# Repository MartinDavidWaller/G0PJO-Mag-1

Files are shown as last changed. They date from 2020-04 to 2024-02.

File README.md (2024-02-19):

# G0PJO Mag-1

 This is my take on a magnetic iambic paddle.
 
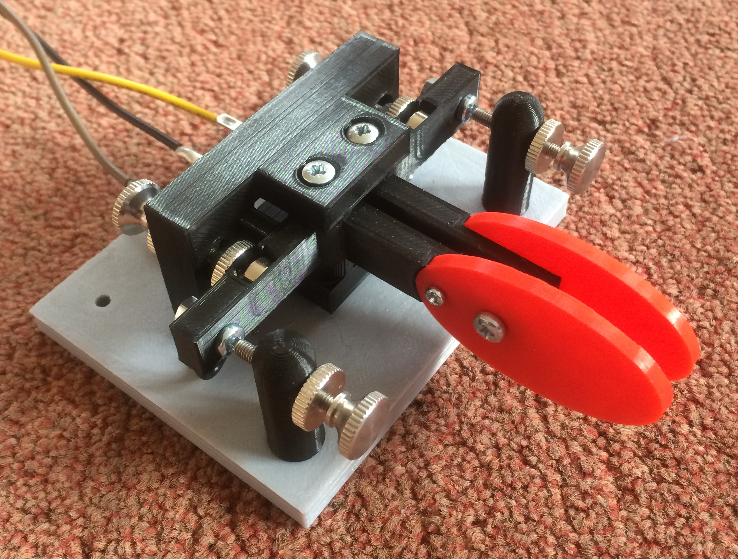
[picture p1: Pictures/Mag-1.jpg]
  
 
 For a demo click the following like: <https://1drv.ms/v/s!AnVoR6zEVAnDpdU-3a5iHmETETuGXw?e=P3bwG2>
 
 ## Required Parts
 
 The following parts are all 3D printed. The table below details the part, the colour, the infill, 
 and the approximate length, and weight, of PLA required. If parts seem too 'bendy' then you may like to increase
 the infill percentage when printing.

| Part | Colour | Quantity | Infill % | Total Length | Total Weight |
|---|---|---|---|---|---|
| Base | Grey | 1 | 20% | 6.62m |  20g |
| Binding Post	 | Black  | 3 | 20%	 | 0.33m | < 1g |
| Dah Lever Arm | Black  | 1 | 80%	 | 1.62m | 5g |
| Dih Lever Arm	 | Black  | 1 | 80%	 | 1.62m | 5g |
| Lever Plate	 | Red | 2 | 20%	 | 1.56m | 4g |
| Main Frame	 | Black  | 1 | 20%	 | 4.90m |  15g
| Short Contact Post | Black  | 2 | 20%	 | 1.14m | 4g

Total length of PLA required 17.79m, total weight 53g.

The table below details all the additional hardware, nuts & bolts etc.

| Part | Quantity | See Note |
| --- | ---| --- |
| M2 Bolt 6mm | 2 | 1 |
| M2 Nut | 2 | 1 |
| M3 Bolt 6mm | 4 | 1 |
| M3 Bolt 16mm | 7 | 1 |
| M3 Bolt 30mm | 2 | 2 |
| M3 Knurled Bolt 20mm | 4 | 6 |
| M3 Knurled Thumb Nut | 3 | 5 |
| M3 Knurled Nut | 6 | 4 |
| M3 Nut | 17 | 1 |
| M3 Solder Tag | 15 | 1 |
| M3 Washer | 3 | 1 |
| Neodymium Magnets Rare 8mm Diameter by 3mm | 2 | 3 |

Notes:

1. Bought from BitsBox. <https://www.bitsbox.co.uk/>
2. Bought on ebay. <https://www.ebay.co.uk/itm/Pan-Head-M3-Machine-Screws-A2-Stainless-Steel-Phillips-Head-Bolts-Pozi/192055137207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>
3. Bought on ebay. <https://www.ebay.co.uk/itm/Neodymium-Magnets-4mm-5mm-6mm-8mm-10mm-12mm-15mm-neo-magnet-discs-craft-hobby-UK/153421329186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>
4. Bought on ebay. <https://www.ebay.co.uk/itm/Carbon-Steel-Leveling-Round-Knurled-Thumb-Nut-Zinc-Ni-Plated-M2-M2-5-M3-M4-M5-M6/283734043425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> 
5. Bought on ebay. <https://www.ebay.co.uk/itm/M2-M2-5-M3-M4-M5-M6-High-Knurled-Thumb-Nut-Stainless-Steel-Hand-Grip-Knob-Nuts/123896017185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>
6. Bought on ebay. <https://www.ebay.co.uk/itm/Stainless-Steel-Knurled-Thumb-Screws-Hand-Grip-Knob-Bolts-M2-M2-5-M3-M4-M5-M6/283734090984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>

## Assembly

Assembly is quite easy. Below are the steps to follow. The only required tools are a screwdriver and small pliers.

### Step 1

Install 3 binding posts. These provide connections to the keyer. Each post requires:

* M3 Bolt 16mm * 1
* M3 Solder Tag * 1
* Printed Binding Post * 1
* M3 Knurled Thumb Nut * 1
* M3 Nut * 1
* M3 Washer * 1

Expect to bury the nut within the body of the binding post. See the images below for the detailed construction. 

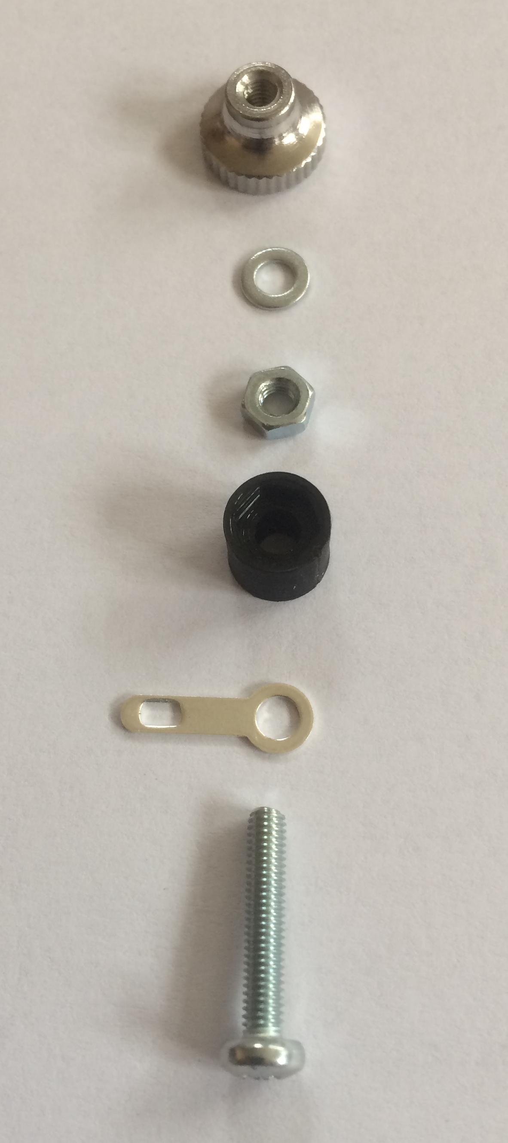
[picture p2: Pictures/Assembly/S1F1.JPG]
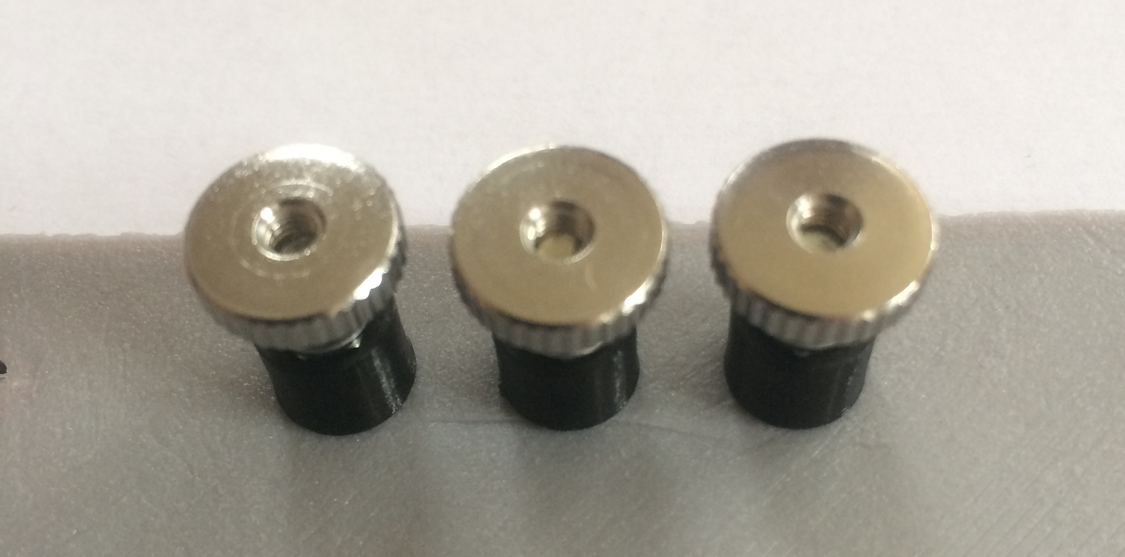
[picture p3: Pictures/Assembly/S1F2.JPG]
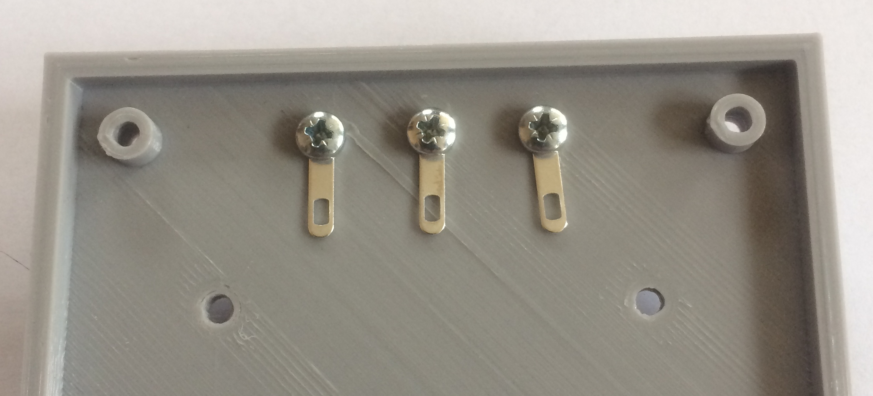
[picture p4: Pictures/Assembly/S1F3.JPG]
  

### Step 2

Build the two arms. Each arm requires:

* Arm * 1
* Lever Plate * 1
* M2 Bolt 6mm * 1
* M2 Nut 
* M3 Bolt 6mm * 2
* M3 Nut * 2
* M3 Solder Tag * 1
* Neodymium Magnet * 1

Expect to bury the nuts within the arms. If you have a problem inserting the nuts into the arm then simply 
use a longer bolt to pull them in to the arm. See the images below for the detailed construction. 

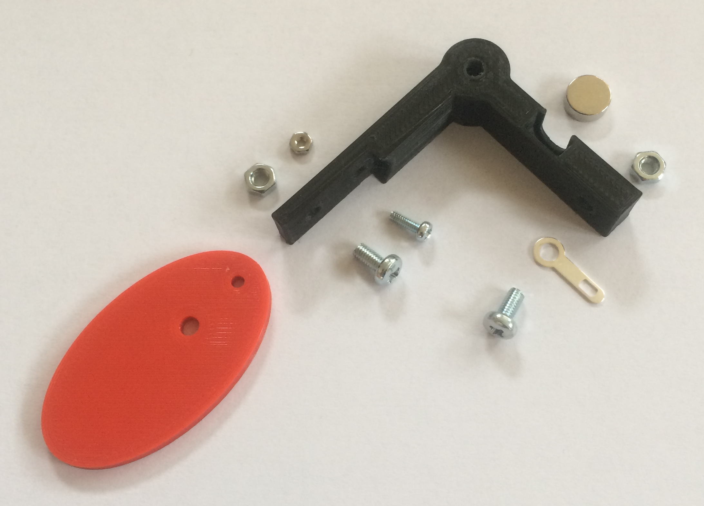
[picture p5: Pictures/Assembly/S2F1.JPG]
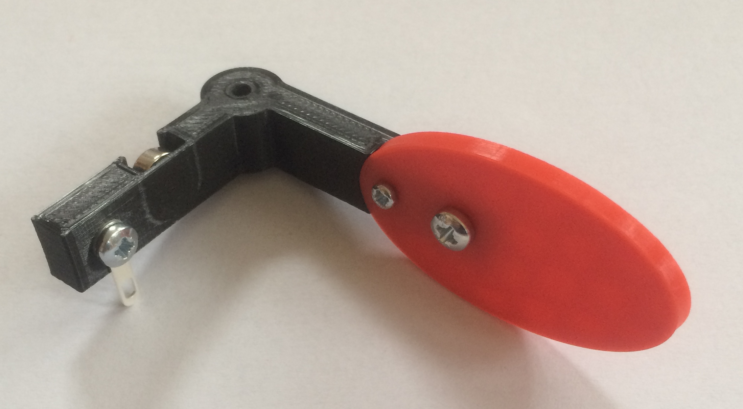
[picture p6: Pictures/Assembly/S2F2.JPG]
  

### Step 3

Assemble the two magnet attraction bolts. Each bolt requires:

* M3 Knurled Bolt 20mm * 1
* M3 Knurled Nut * 2
* M3 Nut * 2

See the images below for the detailed construction. 

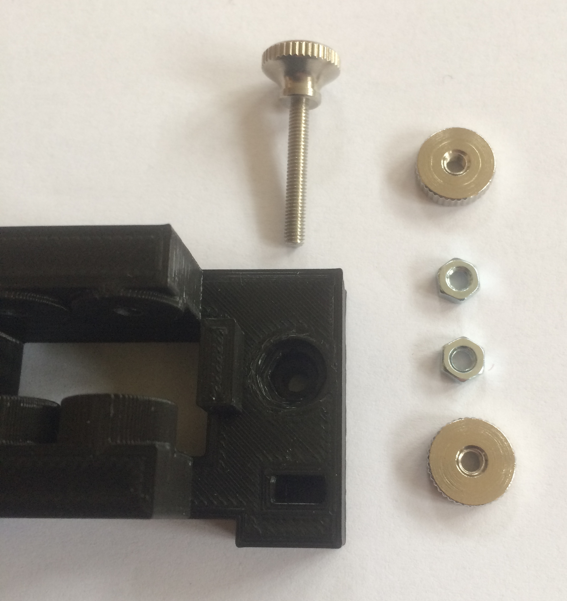
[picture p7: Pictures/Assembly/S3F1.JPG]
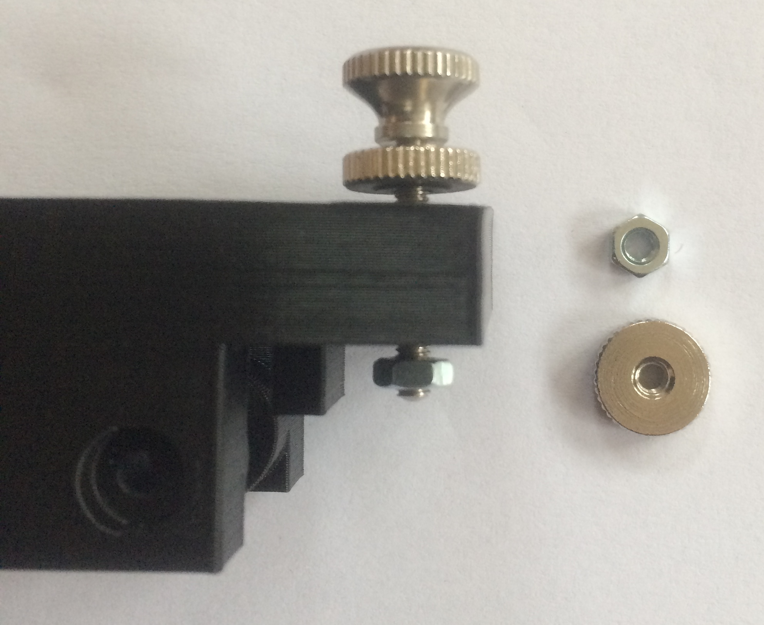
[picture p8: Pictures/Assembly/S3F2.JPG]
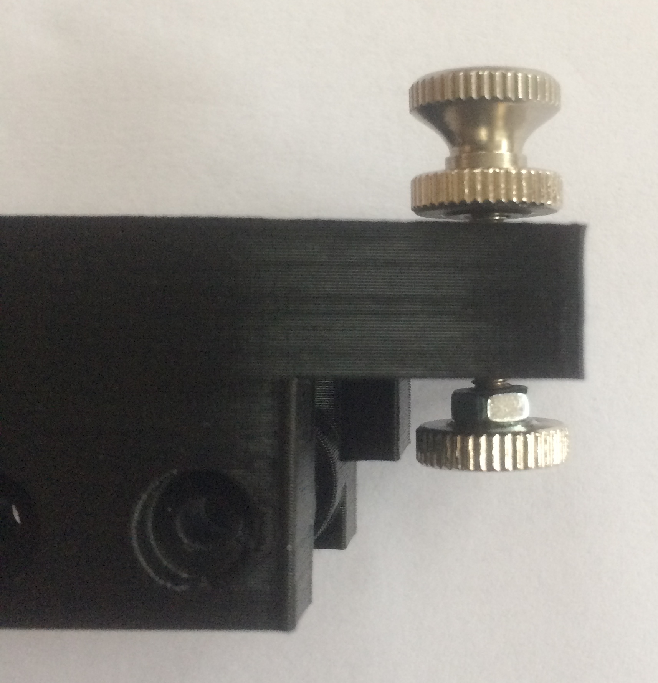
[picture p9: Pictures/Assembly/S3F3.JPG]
   

### Step 4

Assemble the two signal contacts and attach the frame to the base place. Each side requires:

* M3 Bolt 16mm * 2
* M3 Nut * 1
* M3 Solder Tag * 2

The M3 bolt goes through an M3 solder tag, through the base plate into the body, 
though an M3 solder tag and then through the M3 bolt.
See the images below for the detailed construction. 

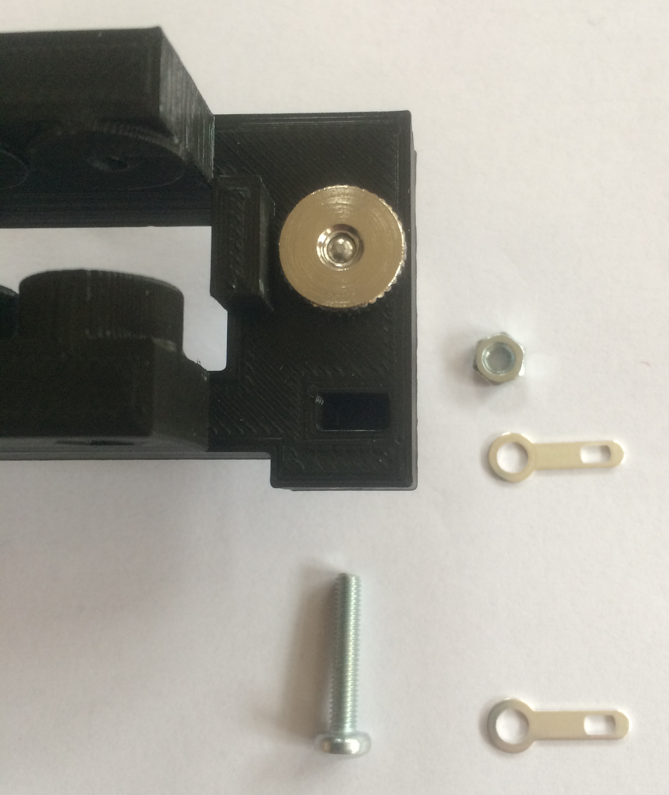
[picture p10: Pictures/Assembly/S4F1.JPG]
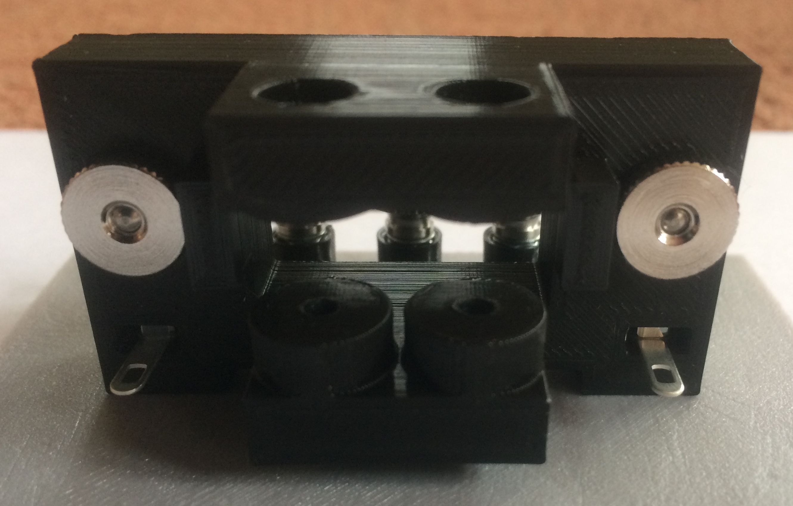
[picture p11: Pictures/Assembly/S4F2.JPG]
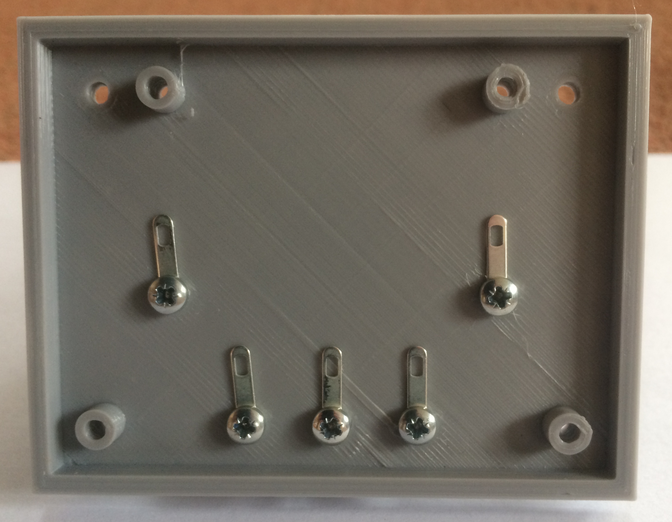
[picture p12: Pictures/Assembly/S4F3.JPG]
   

### Step 5

Assemble the DIT and DAH short contact posts. Each post requires:

* M3 Knurled Bolt 20mm * 1
* M3 Knulred Nut * 1
* M3 Solder Tag * 2
* M3 Nut * 2
* M3 Bolt 16mm * 1
* Printed Short Contact Post * 2

Starting at the top put the knurled nut onto the knurled bolt and screw it all the way down. 
Pass the bolt thought the 3mm hole in the side of the contact post and put one M3 solder 
tag and 3mm nut on the other size and screw home so that the nut is pulled into the contact 
post. At the bottom push the hoop end of a 3mm solder tag into the contact post and above 
that push in a M3 nut. Screw the M3 bolt up through the bottom until it has passed through
the nut. You should then be able to bend the bottom 3mm solder tag over the M3 nut so that 
it makes contact with the upper M3 solder tag. The solder tag can then be soldered together. 
This can be done in situ, but it is best to disassemble and solder them separately.
See the images below for the detailed construction.

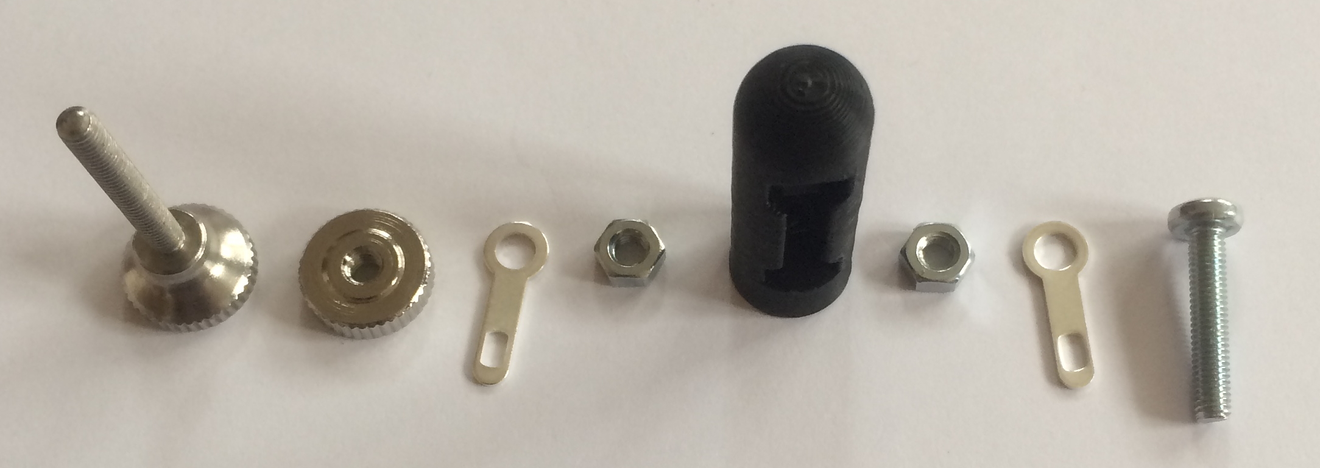
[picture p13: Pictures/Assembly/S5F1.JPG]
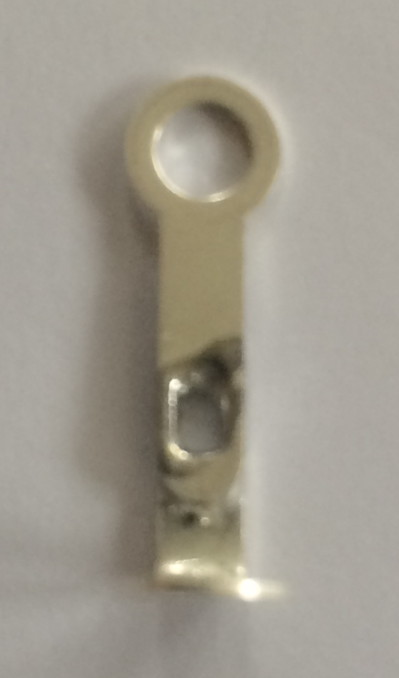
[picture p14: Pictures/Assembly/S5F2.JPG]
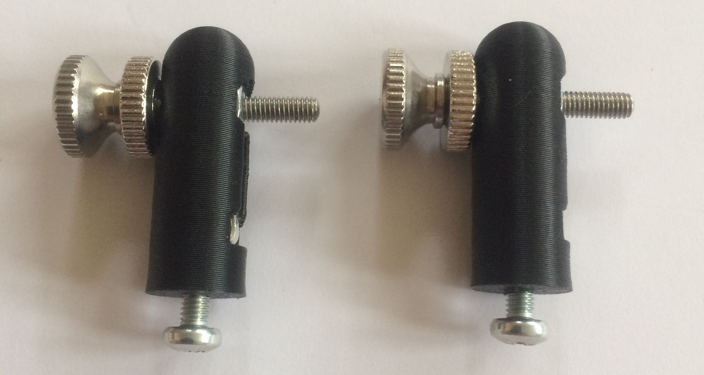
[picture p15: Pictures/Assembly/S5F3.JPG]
  

### Step 6

Attach the DIT and DAH short contact posts to the base. Each post requires:

* M3 Solder Tag * 1
* M3 Bolt 16mm * 1

Pass the bolt through an M3 solder tag and up through the base and into the base of the short contact post. Tighted as required.
See the image below for the detailed construction.

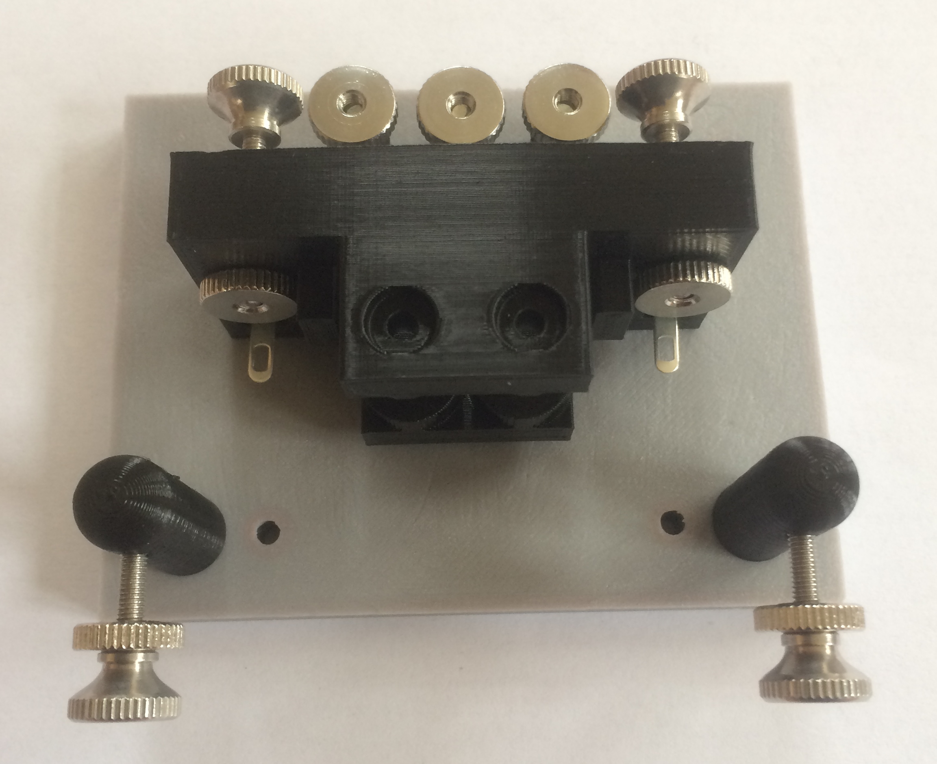
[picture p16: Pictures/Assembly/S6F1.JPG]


### Step 7

Attach the DIT and DAH short arms to the body. Each post require:

* M3 Bolt 30mm * 1

Align the hole in the arm with the hole in the body and drop in the M3 bolt. When adjusted there is sufficient friction to keep
the bolt, and hence the arms in place. There is provision in the bottom of the body for nuts on these two bolts but they
were found not to be necessary. You may need to slightly enlarge these holes with a 3mm drill. If required try to follow the pilot
hole as closely as possible. See the image below for the detailed construction.

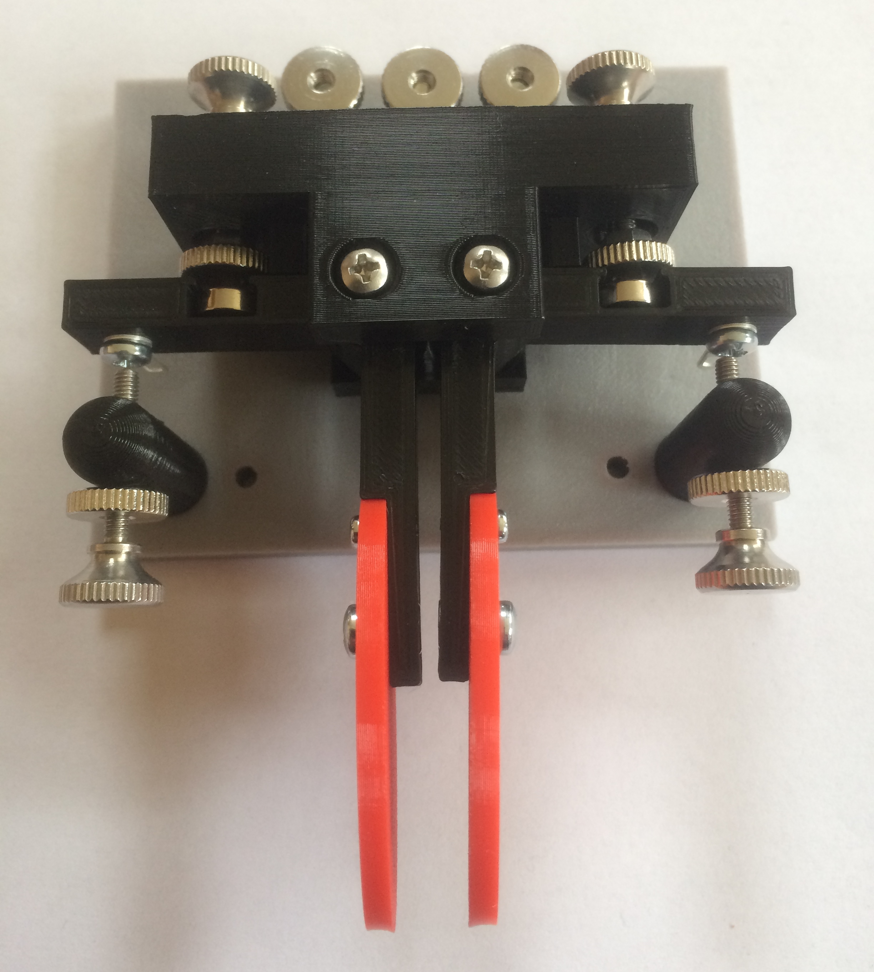
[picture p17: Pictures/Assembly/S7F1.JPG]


### Step 8

Add hook up wires. This requires:

* Assembled keyer * 1
* Short lengths of hook up wire, preferably multi strand.

This is best described by the images below. 

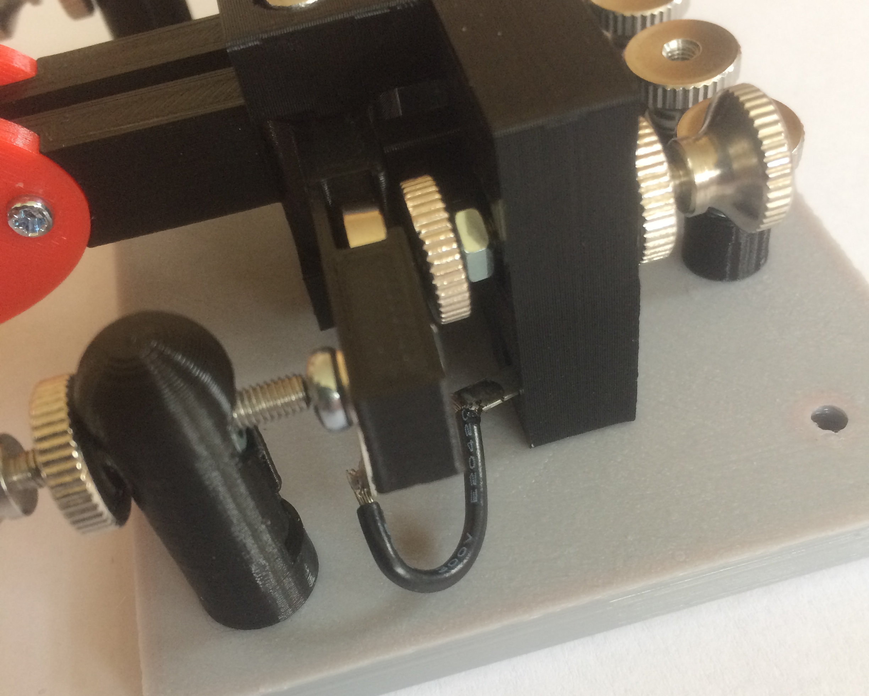
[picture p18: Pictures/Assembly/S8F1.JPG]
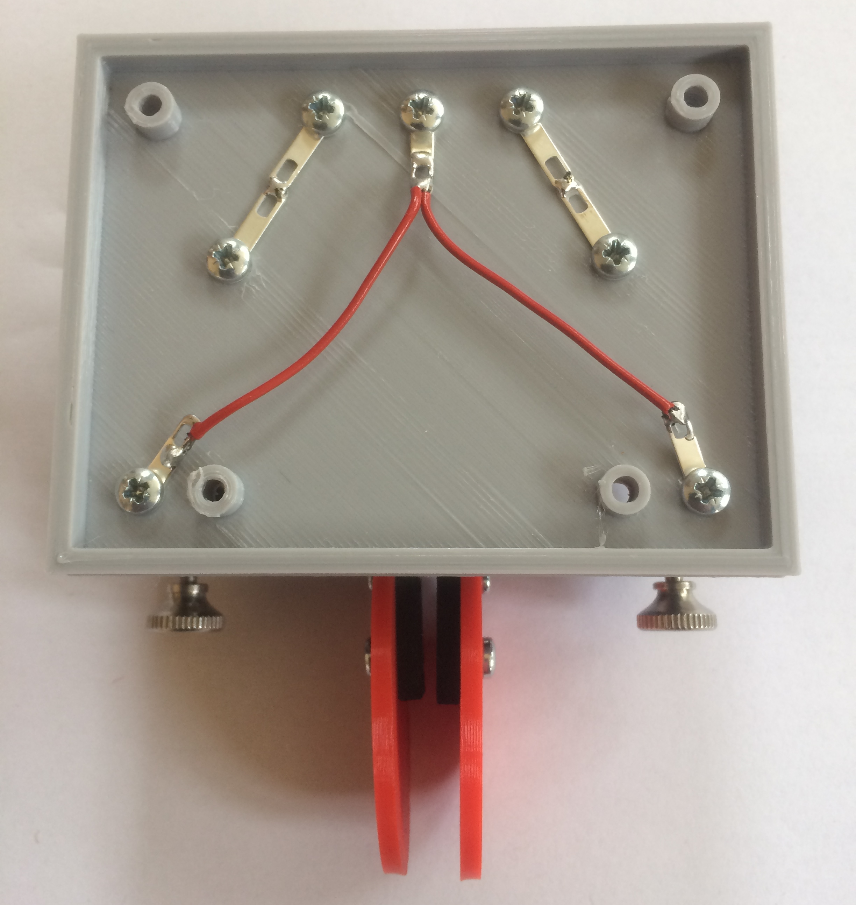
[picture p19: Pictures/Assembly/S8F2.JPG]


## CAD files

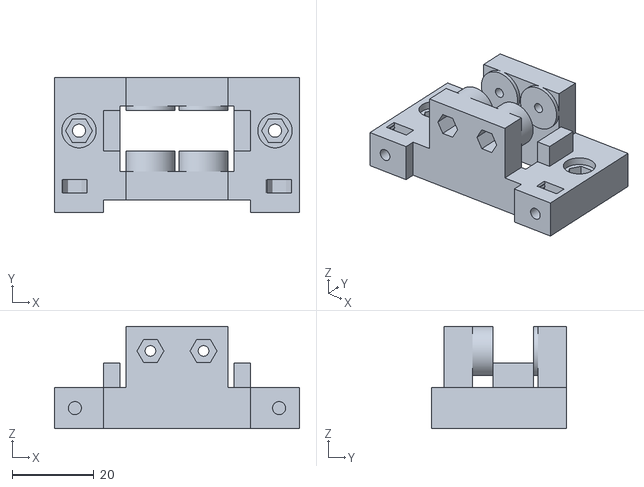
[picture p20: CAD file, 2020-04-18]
STL/MainFrame.stl
60.0 x 33.0 x 25.0

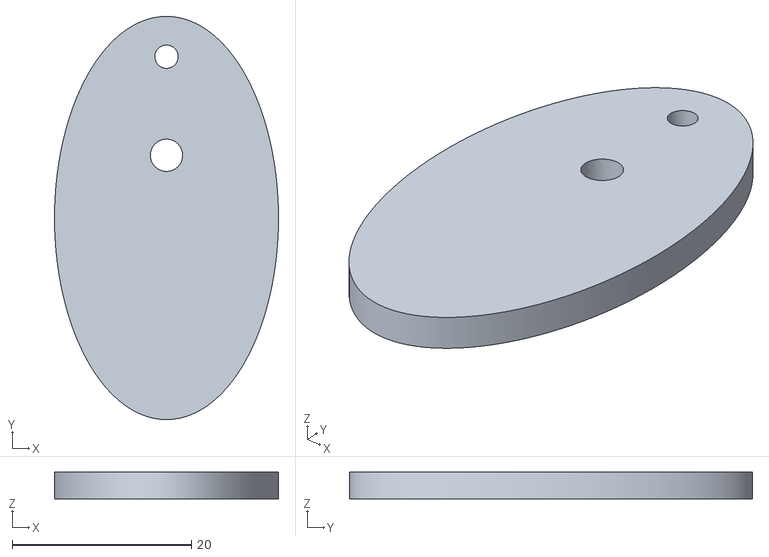
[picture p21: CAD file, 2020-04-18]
STL/LeverPlate.stl
25.0 x 45.0 x 3.00

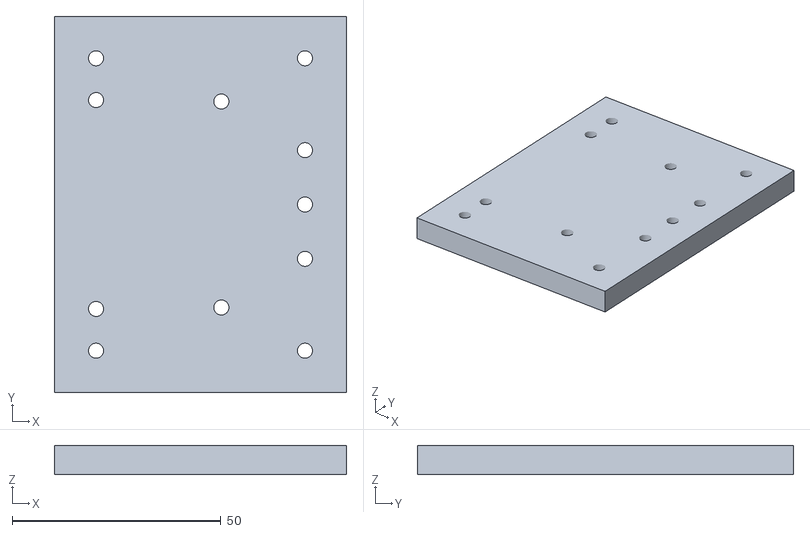
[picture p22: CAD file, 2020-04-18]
STL/Base.stl
70.0 x 90.0 x 7.00

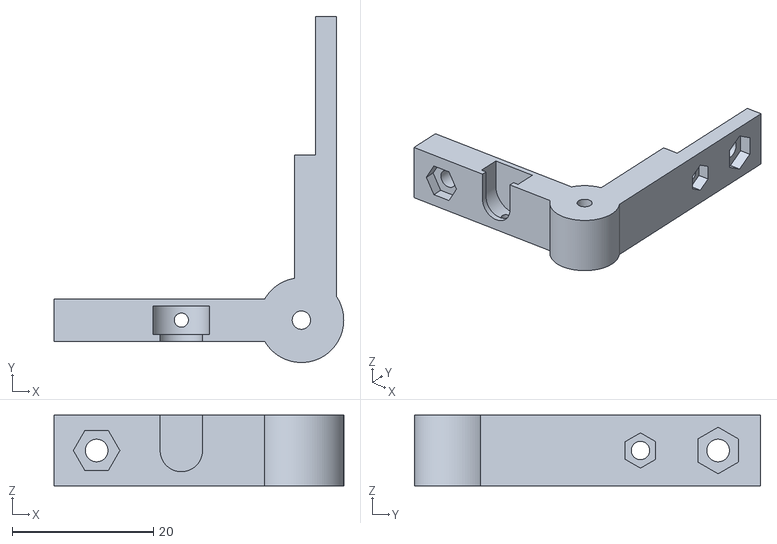
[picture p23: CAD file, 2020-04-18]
STL/Dah Arm.stl
41.0 x 49.0 x 10.0

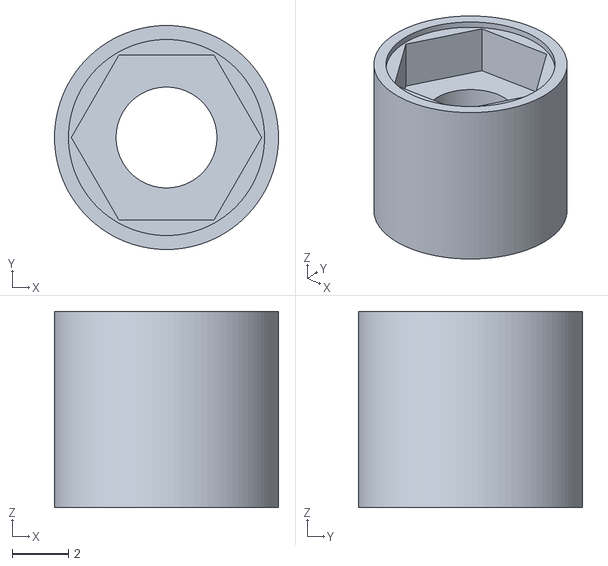
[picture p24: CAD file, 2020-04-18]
STL/BindingPost.stl
8.00 x 8.00 x 7.00

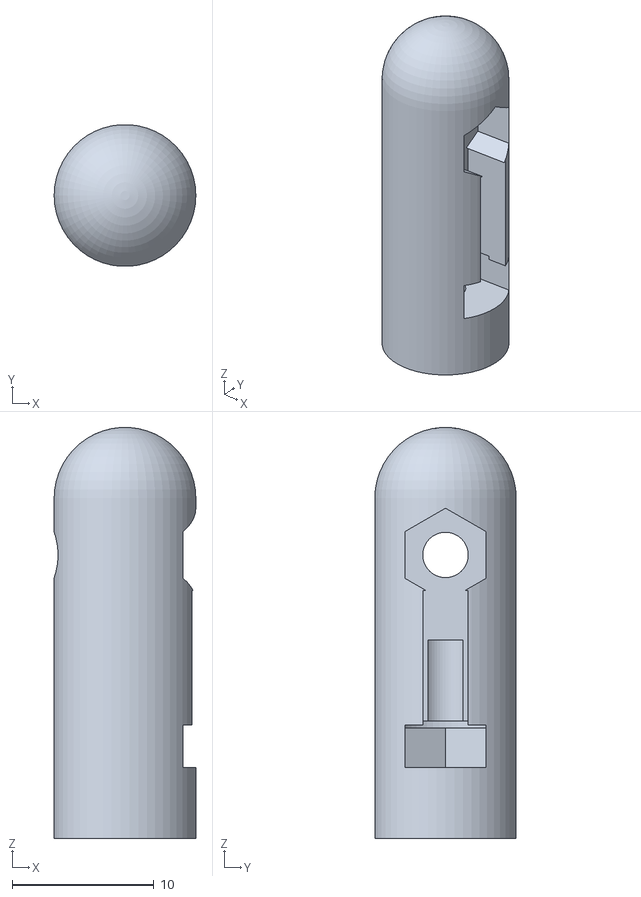
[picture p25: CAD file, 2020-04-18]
STL/ShortContactPost.stl
10.0 x 9.98 x 29.0

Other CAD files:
STL/Dit Arm.stl

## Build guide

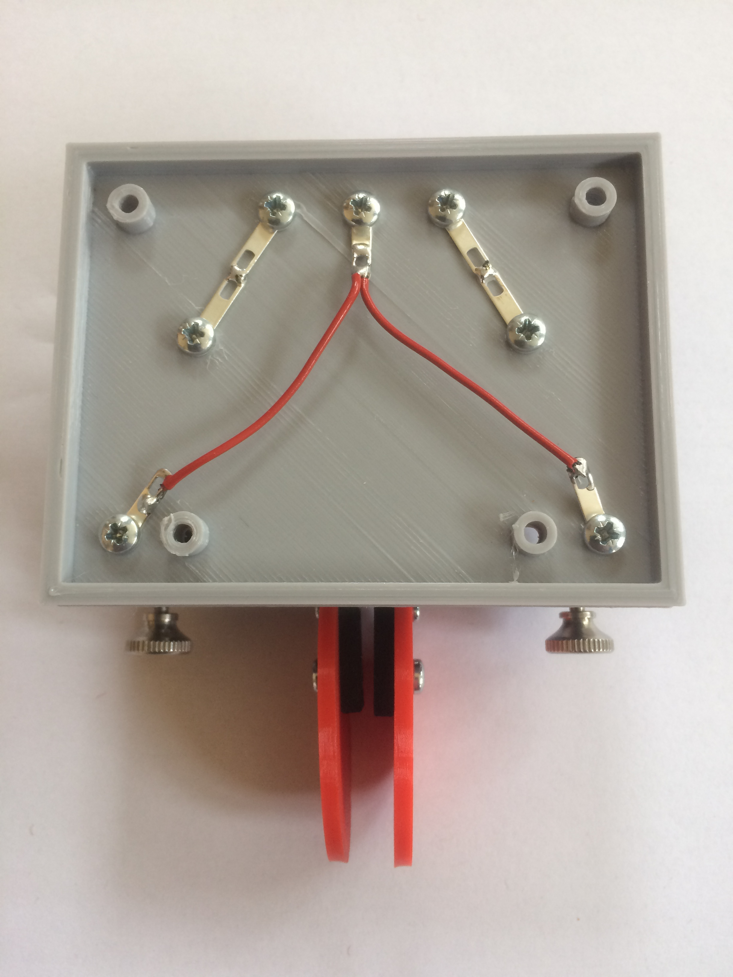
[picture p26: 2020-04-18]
Pictures/Assembly/IMG_1425.JPG

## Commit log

2020-04-18 Assembly update
2020-04-18 Added STL folder
    [Base.stl, BindingPost.stl, Dah Arm.stl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]
